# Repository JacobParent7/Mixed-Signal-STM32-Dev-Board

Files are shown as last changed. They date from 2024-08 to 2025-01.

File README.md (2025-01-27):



# Mixed-Signal-STM32-Dev-Board

This project follows the  [Mixed-Signal Hardware Design with KiCad](https://fedevel.com/courses/mixed-signal-hardware-design-with-kicad) 4-layer PCB design course instructed by Philip Salmony of the Phil's Lab youtube channel.  

Thank you to PCBWay for sponsoring the PCB fabrication and assembly for this complex mixed-signal board! 

Check our their services at https://www.pcbway.com/

0x0-2426178651

## System Level Description
### Basic Requirements
    - USB powered, single channel, low frequency analysis and generation capabilities
    - Perform frequency analysis and arbitrary signal generation
### Feature Specific Requirements
    - USB - <500mA current consumption 
    - Low Frequency - 20Hz - 20kHz (audio band)
    - ADC and DAC (or codec) for analysis and generation, single channel 
### Simple Block Diagram  
SimpleBlockDiagram
### Refine requirements
    - USB - low bandwidth and transfer requirements
    - Sample at Nyquist limit (40kHz)
    - Choose higher resolution ADC to minimize quantisation error
datarate
### USB Standard
    - Full Speed - Up to 12 Mbits/s (this is plenty enough)
    - High Speed - Up to 480 Mbits/s
    - System is bus powered (not a host) and will most likely require <500mA
    - Use type C, new universal standard
### Processor
    - Low bandwidth and storage requirements so FPGA unnecessary
    - Use MCU
        - C easy compared to Verilog
        - SWD or JTAG protocols available 
    - Peripherals
        - USB for data stream
        - SPI for ADC and DAC
    - Required Power?
        - Cortex M0 should be adequate 
        - Avoid BGA or QFN packages (too expensive and benefits not necessary for our use case) 
        - I know STM32 platform well
### PSU
    - Digital Circuitry Supply
        - Switch mode supply is noisy but more efficient than LDO. Works for resillient digital circuitry
    - Analog Circuitry Supply
        - LDO for low noise
        - Less current required compared to digital circuitry typically
    - Power from USB
        - Must regulate due to noise
        - +5V nominal, can drop to +4.5V
        - 500mA can be negotiated, but 150mA is default so design for that

### Simple Converter Theory
    - Higher bits gives better signal to noise ratio
    - Higher sampling rate provides less aliasing with a higher Nyquist limit, however this produces more data to store, process, and stream
    - Consider using oversampling and antialiasing filters on the convert ICs themselves
    - Interface with SPI since data rate is low (typical for microcontrollers)
    
### Analog Circuitry for Converters
    - ADC
        - High-impedance (don't attenuate original signal), ESD protection, RF filtering
        - Antialiasing filter at 1/2 the sampling frequency (Nyquist Rate)
        - Single ended vs differential compatibility
    - DAC
        - Low-impedance with output buffer for driving a load
        - Antialiasing filter at 1/2 the sampling frequency (Nyquist Rate) 
        - Single ended vs differential compatibility

### Miscellaneous Requirements
    - Mechanical Constraints
        - PCB dimensions
        - Mounting Holes
        - Connector Placement
        - Conductive Case?
    - Connectors
        - Debugging interface
        - IO types (SMA, BNC)
    - Peripherals
        - LEDs?
    - Other
        - Timing
        - ESD protection
        - EMC filtering
        - Biasing for analog circuitry 
### Final Block Diagram
finalblockdiagram

## Schematic Design - Power


### Input Pi Filter
    - The input RLC Pi filter from the USB-C has an inductor with a DC resistance of 0.15 Ohms and max DC of 0.5A
    - http://sim.okawa-denshi.jp/en/Fkeisan.htm -> Tools for filter design 
    - Using the website, we can see the Pi Filter has a cutoff in the 1.6 MHz range. For PSU, we want to keep the cutoff high to dampen high frequency noise
    - Be careful; IC transients are hungry for high frequency current and you don't want to starve them. Cutoff only what is needed to pass EMI tests. 
    


### Analog LDO regulator - HT75xx
    - Datasheet says to use at least 10uF for input and output caps. We use 22uF to avoid issues due to tolerances and voltage derating. 
    - Series Input resistor with at least 1/8W power rating creates low-pass filter RC with 22uF input capacitor
    - In general, RC filters have a much shallower roll-off compared to the RLC Pi Filter. They also have significant Johnson noise. 
    - Input low-pass has cutoff at 723 Hz. This is low but okay because it feeds a low freq analog supply. 

### Buck Converter
    - Main external circuitry
        - Input caps
        - Output LC filter - use below formula to calculate inductor value
        - Feedback network (formula straight from datasheet and also in schematic) 
        - Sometimes external FETs and diodes
#### [Choosing Inductor Value]
        - Delta IL is ripple current - try to get 20% - 30% of max output current
        - Design for worst case
            - Larger Vin
            - Low current loads
        - Choosing larger inductor than initially calculated
            - +- 20% typical tolerance
            - Max DC and sat current need to be higher than what we require in our worst peak current case (250mA)
            - Low current loads (down to 50mA) will require larger inductors
            - Is shielding important to us?
        - Plotting below function in DESMOS we see lighter loads require much larger inductance (6x) what we calculated, so we chose a 68 uF inductor
        - Although datasheet says we can use 4.7uF minimum caps, we want to consolidate our BOM, so choose 22uF as required by LDO
#### [DNP???]
    - We have a DNP (Do not place) cap because the datasheet recommends it for stability and speed
    - We still want the option to place it, so we will put pads on the PCB for it. 


### Bias Generator
    - We have a single supply 0V -> 3.3 V
    - Bias an input to 1/2 VA to give max swing potential for superimposed AC signal 
    - Provide bypass cap as recommended by datasheet (place physically close on board)
    - In high freq designs, the voltage and ground planes seperated by a dielectric board material create a low value high speed capacitor. 

## Schematic Design - MCU

### MCU Digital Power Decoupling
    - As recommended by the datasheet, we have a 100uF cap for each digital power input for a total of four caps
    - We also have on 10uF bulk decoupling cap, also recommended by the datasheet


### MCU Analog Power Decoupling
    - We do not need to do this because we are using external DAC and ADC
    - Below shows the datasheet implementation if this were not the case


### Config pins and Crystal Oscillator
    - NRST typically pulled high by internal 40k resistor. Route to SWD header for more control
    - BOOT0 on most STM32 uC. Tells chip to either run program flashed (low) or to listen for debug signals on UART or USB (high)
    - HSE_IN and HSE_OUT are our STM32 chips pins for an external crystal oscillator. Internal osc is okay for some applications, but not really accurate enough for UART or USB communication. 
    - The load capacitance (10p), ESR, and frequency of the crystal can all be found in the datasheet. 
    - For more info on calculating load caps, find AN2867 design guide for crystal oscillators. 



## Microcontroller Pin Layout
    - The datasheet for any given uC will specify what functions the uC pins can serve. However, we can take advantage of the STM32 Cube IDE to do this for us and save time
### Pin layout description
    - Under SYS, set up serial wire debug for communication. Choose trace asynchronous Sw for live plotting or monitoring.
    - Under RCC, choose HSE to be crystal resonator for external circuitry
    - Under TIM, we can choose timer channels for PWM generation for LEDs. 
    - Under connectivity, set up receiving and transmitting master SPI channels for ADC and DAC. Choose check box under USB for full speed USB.



### Moving to KiCAD
    - Once you choose the desired pin configuration in Cube IDE, move back to KiCAD and map pins to schematic symbol shown below
    - Add pull up resistors on SPI hardware and chip select lines (not necessary if driven by GPIO), however, we are using hardware chip select pin from SPI drivers
    - On USB diff pair, name + and - to tell KiCAD to map as diff pair.
    - Check application note for STM32F1 to see if embededded pullup is included on D+ line. When we check our application note, we can see that an external 1.5 KOhm pullup is required.


## USB, RGB LED, and SWD header

### RGB LED
    - simple 1k current limiting resistors, chosen mostly for BOM consolidation since we are driving using PWM
    - decoupling capacitor since the LEDs are driven by PWM



### USB connector
    - Power and data connections are main 
    - USB C has more pins than typical USB A
    - Read AN4879 application note for specefics on USB layout
    - Supply is noisy, so use a filter like a Pi Filter and RLC filter (seen in PSU section above) 
    - Add ESD protection with low capacitance since we are using a relatively high bandwidth 
    - Data line filtering via common-mode choke will reduce signal integrity but improve EMC performance (not really needed for USB 2.0)
#### USB Type C specifics
    - TA0357 application note from ST
    - Instead of drawing 5V at 5mA, we can use a type C power delivery IC and get 100W (5A at 20 V). This is not required for our project.
    - Tell host we want to draw power by having seperate 5.1k pulldown resistors on CC1 and CC2 pins, where CC stands for configuration channel (Make sure to use two seperate resistors!)
#### Common mode choke specifics
    - Choke must be rated for USB 2 frequency range and not impede too much
    - Choke will have a differential impedance which must match the USB bus impedance (90 Ohm)
#### Specify signal path for readability 
    - Connector -> ESD -> CM Choke -> Pull-Up -> MCU



### SWD Header
    - Look up SWD pinout on google for easy specification
    - SWD is a simple in-circuit debugging and programming method that requires only data and clock lines
    - ST uses ST-Link to make debugging very easy 
    - Include bi-directional TVS diodes on signal lines for protection 
    - Low-pass filter included on NRST line to prevent unwanted resets due to high frequency noise
#### SWD signals explained
    - Main signals are SWDIO and SWCLK
    - SWDIO is bidirectional data
    - SWCLK is clock signal 
    - SWO is an optional signal (trace line from earlier) which allows us to trace output in real time
    - NRST is a pin that if pulled low triggers a hard reset



## ADC & Analog Front End

### ADC IC
    - ADC schematic follows design suggestion from datasheet
    - Seperate Bulk decoupling caps for analog and digital power (use similar caps for BOM consolidation)
    - Shared ground (not good idea to split mixed signal ground)
    - Clock signal has 0 Ohm resistor. Series resistor may reduce EMI and ringing (replace with 22 Ohm for example)
    - Dedicated 3.3V analog reference (U3D2) significantly improves ADC accuracy 
    - PI network used to filter noisy 5V bus from USB. Choose resisitor wisely based on current sink from analog reference. 
ADC

### ADC Front-End
#### Front-End Role
    - Impedance conversion (low to high impednace input)
    - Anti-aliasing filter
#### Componenet Selection (From left to right)
    - BNC standard connector
    - ESD Protection from TVS diode
    - Perform RF filtering (AM or FM radio) @ 1.1 Mhz
    - 1k series resistor garuntees 1k minimum for lowpass filter, although it is likely the connecting device can provide higher impedance
    - C301 acts as decoupling cap for the single power rail Op-Amp
    - R301 and R302 in parallel create input impedance of 1.1 MOhm. This high impedance prevents loading the input
    - R301 and R302 are not in series with the signal path and are simply bias setting resistors. Therefore, they contribute little to Johnson Noise despite their large value. 
    - VCOM is from bias generator in PSU section 
    - R301, R302. and C301 form a high pass filter @1.4 Hz
    - First Op-Amp acts as follower (unity gain high impedance CMOS buffer). Power rail required decoupling cap 
    - Second Op-Amp is a third order sallen-key filter topology. Read below section for more info.
    - Feed resistor (R306) protects from shorts and forms a RC lowpass
    - We want to use single ended, so ADC_IN + and - need a common mode DC. 
#### Sallen-Key filters
    - Active filter (VCVS filter)
    - Low pass anti-aliasing (or reconstruction for DAC) filter
    - Limit bandwidth of sampled signal 
    - Cutoff set to nyquist limit
    - Our filter is a 3rd order (look at # of filtering caps) butterworth coefficient type filter with cutoff @ 25 kHz
    - Butterworth gives maximially flat response as opposed to Chebyshev (roll-off) or Bessel (time-domain responses)
    - http://sim.okawa-denshi.jp/en/Sallenkey3Lowkeisan.htm -> design tool

ADC2

## DAC & Output Stage
    - Second output pulled to ground to reduce noise
    - Internal ref is used for simplicity, decoupled according to datasheet
    - Digital supply used to keep analog supply clean 
    - Same 3rd order Sallen-Key anti-aliasing reconstruction filter
    - DAC outputs do not require AC coupling because bias is generated by the DAC input
    - 50 Ohm output impedance to define Op-AMp output
    - TVS for BNC ESD protection 
DAC

## PCB Layout Specifications

### PCB Stack-Up
    - SIG | GND | VCC | SIG
        - Easier for routing
    - SIG | GND | GND | SIG
        - Energy flows in dielectric between waveguiding copper. Therefore, this setup gives minimal return pad length for signals (single-ended) on both sides. 
        - Routing power through traces is not really a problem for an audio frequency design 
### Trace size rule of thumb    
    - 0.5mm for power
    - 0.3mm for signal
    - Spacing: 3x dielectric thickness to help with crosstalk noise
    - Always minimise length and maximize spacing

### Controlled impedance traces
    - Need to consider if rise/fall times of digital signals or highest frequency of analog signals are comparable to the propagation lengths of the PCB traces
    - High speed digital bus (USB, PCIe,...) and RF should always be routed as controlled impedance
    - We control impedances to match the impedance of the driver and receiver to minimize reflections
    - Trace impedance is approximated by inductance and capacitance of trace
        - Inductance has to do with the area of the loop
        - Capacitance has to do with the suface area
    - Use PCB fab calulator to find width for microstrip and diff pair traces





### Via Sizing
    - Small: 0.45mm pad with 0.25mm drill
    - Mediumn: 0.7mm pad with 0.3mm drill
    - Large: 0.8mm pad with 0.4mm drill
    - Use medium if possible for best cost 
    - Large is good for higher currents and small if contrained for space

## PCB Layout

### MCU
    - Keep decoupling caps as close to associated pins as possible
    - Pullups and downs can be put pretty much anywhere. Put in line with uC pin
    - Crystal oscillator should be kept away from switching components like the PSU


### ADC
    - ADC chip itself has and analog and digital side. We will use this to seperate the remainder of the layout
    - In general, keep loops as short as possible
    - Decoupling as close to IC as possible
    - Try to keep a clean signal line to eliminate stubs
    - Compressed diff pair into t shape which decreased coupling. This is fine because it's really a pseudo diff pair
    


### DAC    
    - DAC is simply just follow same layout as ADC for recontruction filter

### Linear and Switching PSU
    - Follow datasheets for ICs

### Rough Draft Layout Render

Nemesis-MixSigPCB

### Final Layout

    - 5V and 3.3 Power were routed last and planned mostly on the back
    - GND Via inlcuded for every signal or power via since we are using the board build up previously mentioned with 2 GND planes. This reduces EMI. 
    - All signals were routed as 50 Ohms controlled impedance which was 0.29mm. All power traces were 0.5mm
    - Diff pair was routed as .21 mm as calculated on expected manufacturers website. 
    - Digital and Analog portions were kept as far apart as possible
    - Use polygons instead of traces to connect Power that is near each other. 



### What is left?
    - Sticthing vias
    - Cleaner Routing
    - Silkscreen
    - Prepare for manufacturing

### Final 3D Render

Nemesis-MixSigPCB_Final

### Final Manufactured and Assembled PCB
    - Thanks to PCBWay for this flawless PCB. Throughout the manufacturing process, the engineers
    at PCBWay found a few errors in my design which were fixed for no extra cost. The process was quick 
    and I received the PCB soon after placing my order. 



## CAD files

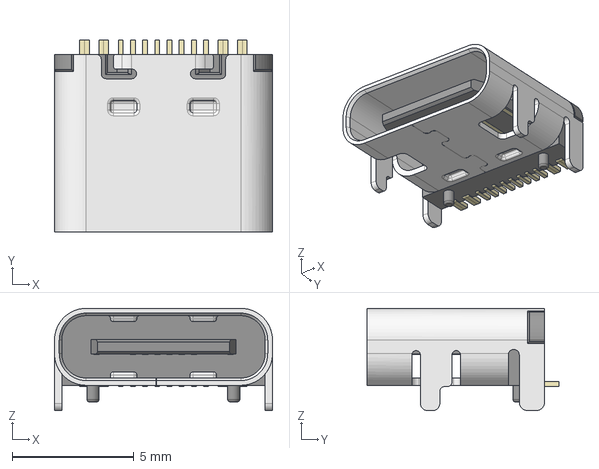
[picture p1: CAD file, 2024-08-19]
HRO_TYPE-C-31-M-12.step
8.95 x 7.90 x 4.20 mm

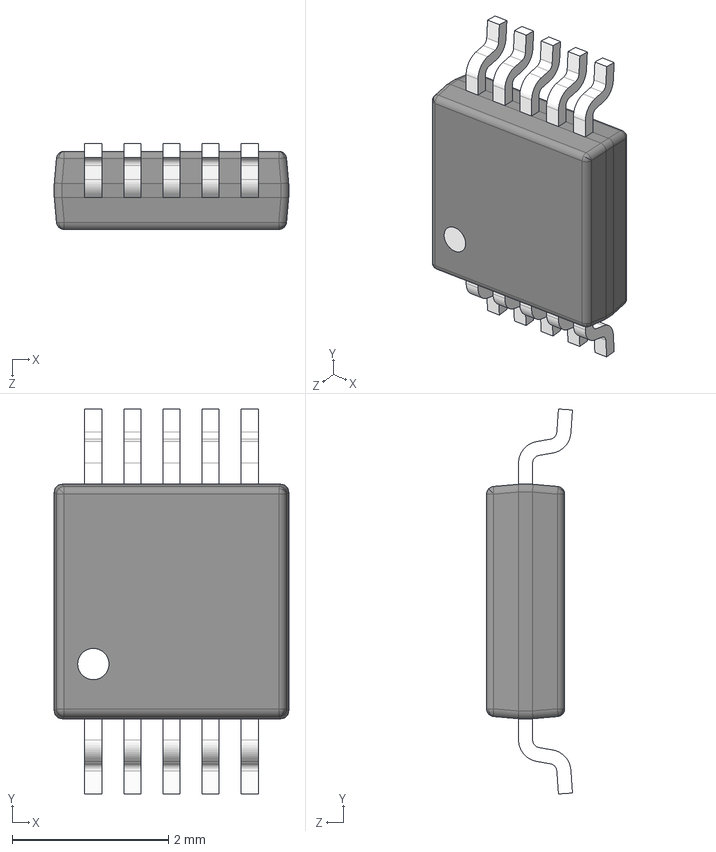
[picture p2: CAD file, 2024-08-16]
User Library-DGS0010A.STEP
3.00 x 4.93 x 1.10 mm
DGS0010A_ASM_LEAD-SO#LEAD-SO;LEAD-SO
DGS0010A_ASM_LEAD-SO#LEAD-SO;LEAD-SO_2
DGS0010A_ASM_LEAD-SO#LEAD-SO;LEAD-SO_3
DGS0010A_ASM_LEAD-SO#LEAD-SO;LEAD-SO_4
DGS0010A_ASM_LEAD-SO#LEAD-SO;LEAD-SO_5
DGS0010A_ASM_LEAD-SO#LEAD-SO;LEAD-SO_6
DGS0010A_ASM_LEAD-SO#LEAD-SO;LEAD-SO_7
DGS0010A_ASM_LEAD-SO#LEAD-SO;LEAD-SO_8
DGS0010A_ASM_LEAD-SO#LEAD-SO;LEAD-SO_9
DGS0010A_ASM_LEAD-SO#LEAD-SO;LEAD-SO_10
DGS0010A_ASM_BODY-SO#BODY-SO;BODY-SO

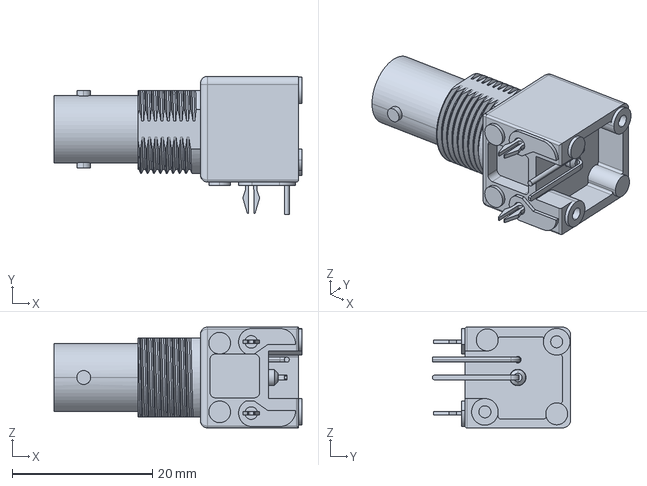
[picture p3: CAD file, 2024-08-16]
bnc.stp
35.4 x 19.8 x 14.4 mm

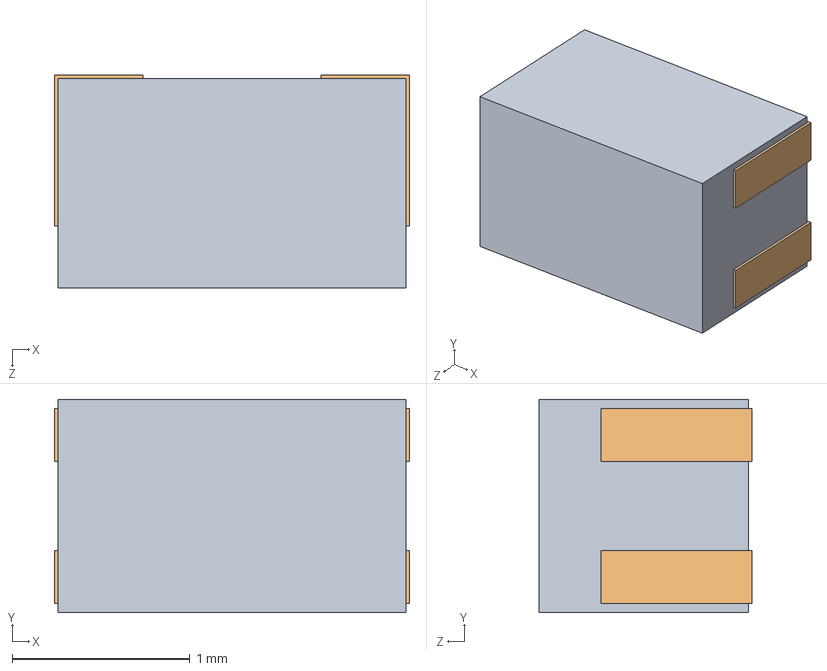
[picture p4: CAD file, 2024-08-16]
ACM2012-900-2P-T.stp
2.00 x 1.20 x 1.20 mm
ACM2012-T002 DRコアブロック(typ size)
ACM2012-T002 電極ブロック(typ size) x 4

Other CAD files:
VSSOP-10.STEP

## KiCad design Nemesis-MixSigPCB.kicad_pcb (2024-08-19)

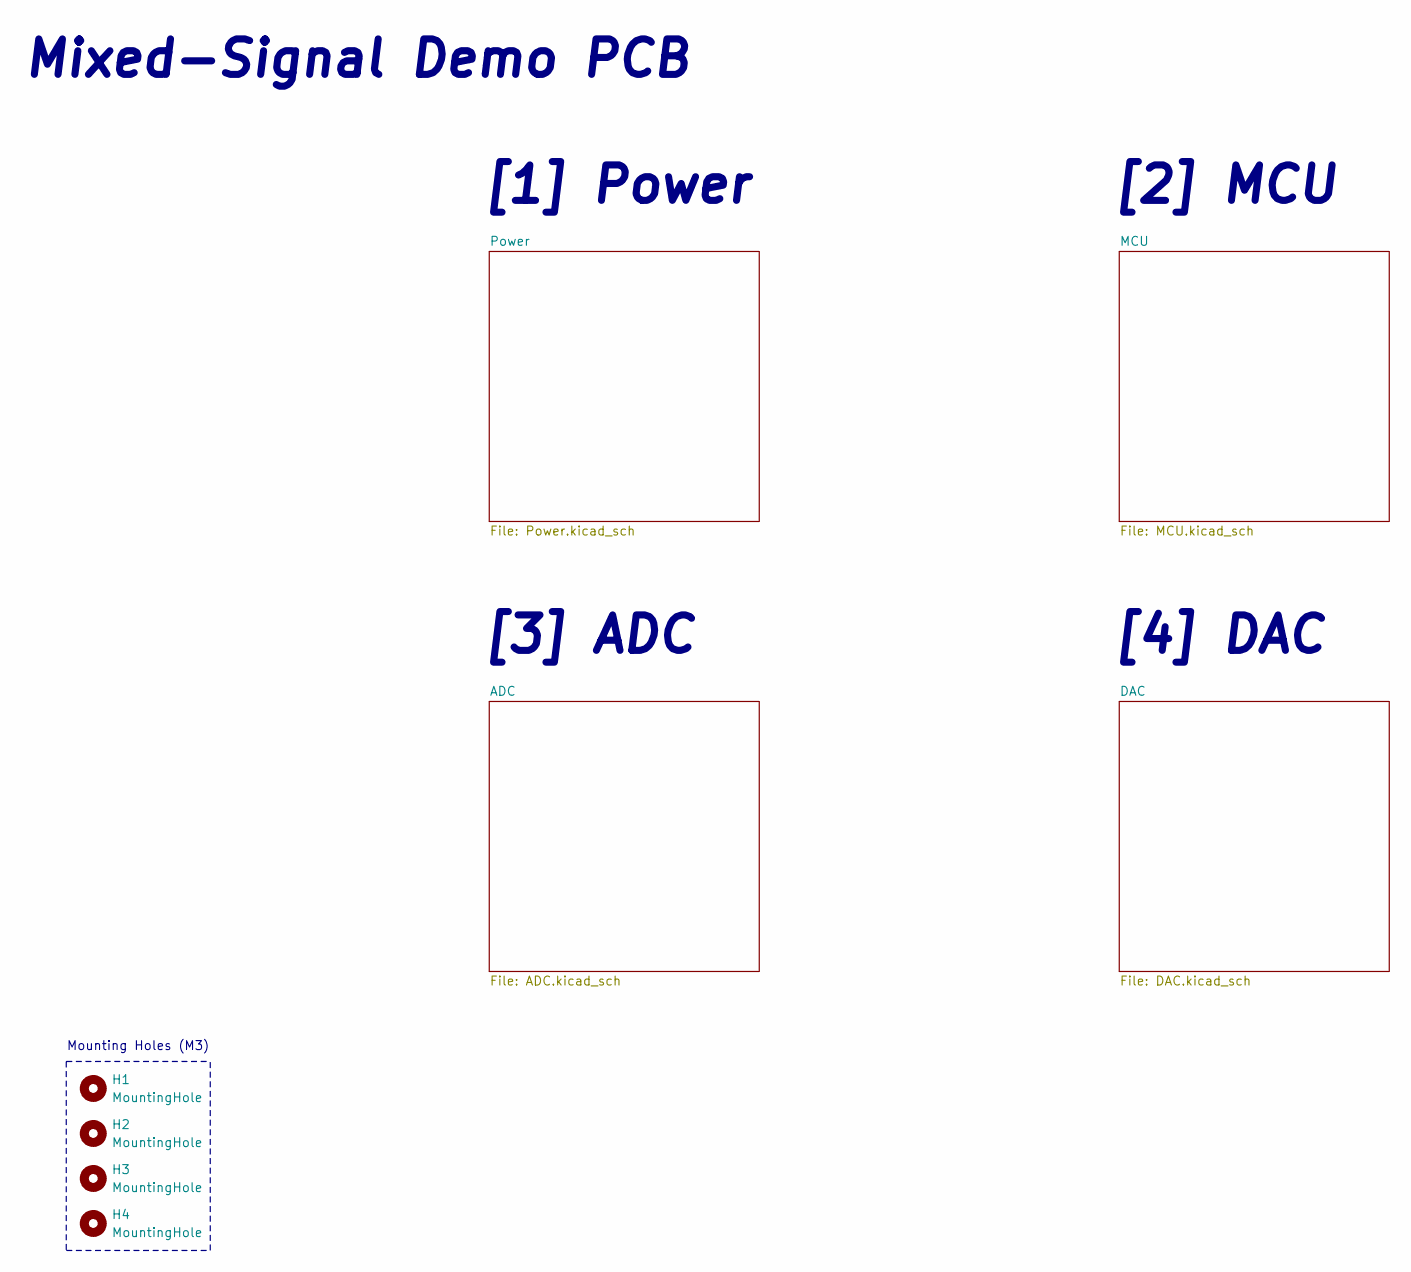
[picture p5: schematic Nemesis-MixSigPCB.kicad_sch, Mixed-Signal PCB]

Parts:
H1, H2, H3, H4: MountingHole; MountingHole_3.2mm_M3

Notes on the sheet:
[4] DAC
Mixed-Signal Demo PCB
[3] ADC
Mounting Holes (M3)
[2] MCU
[1] Power

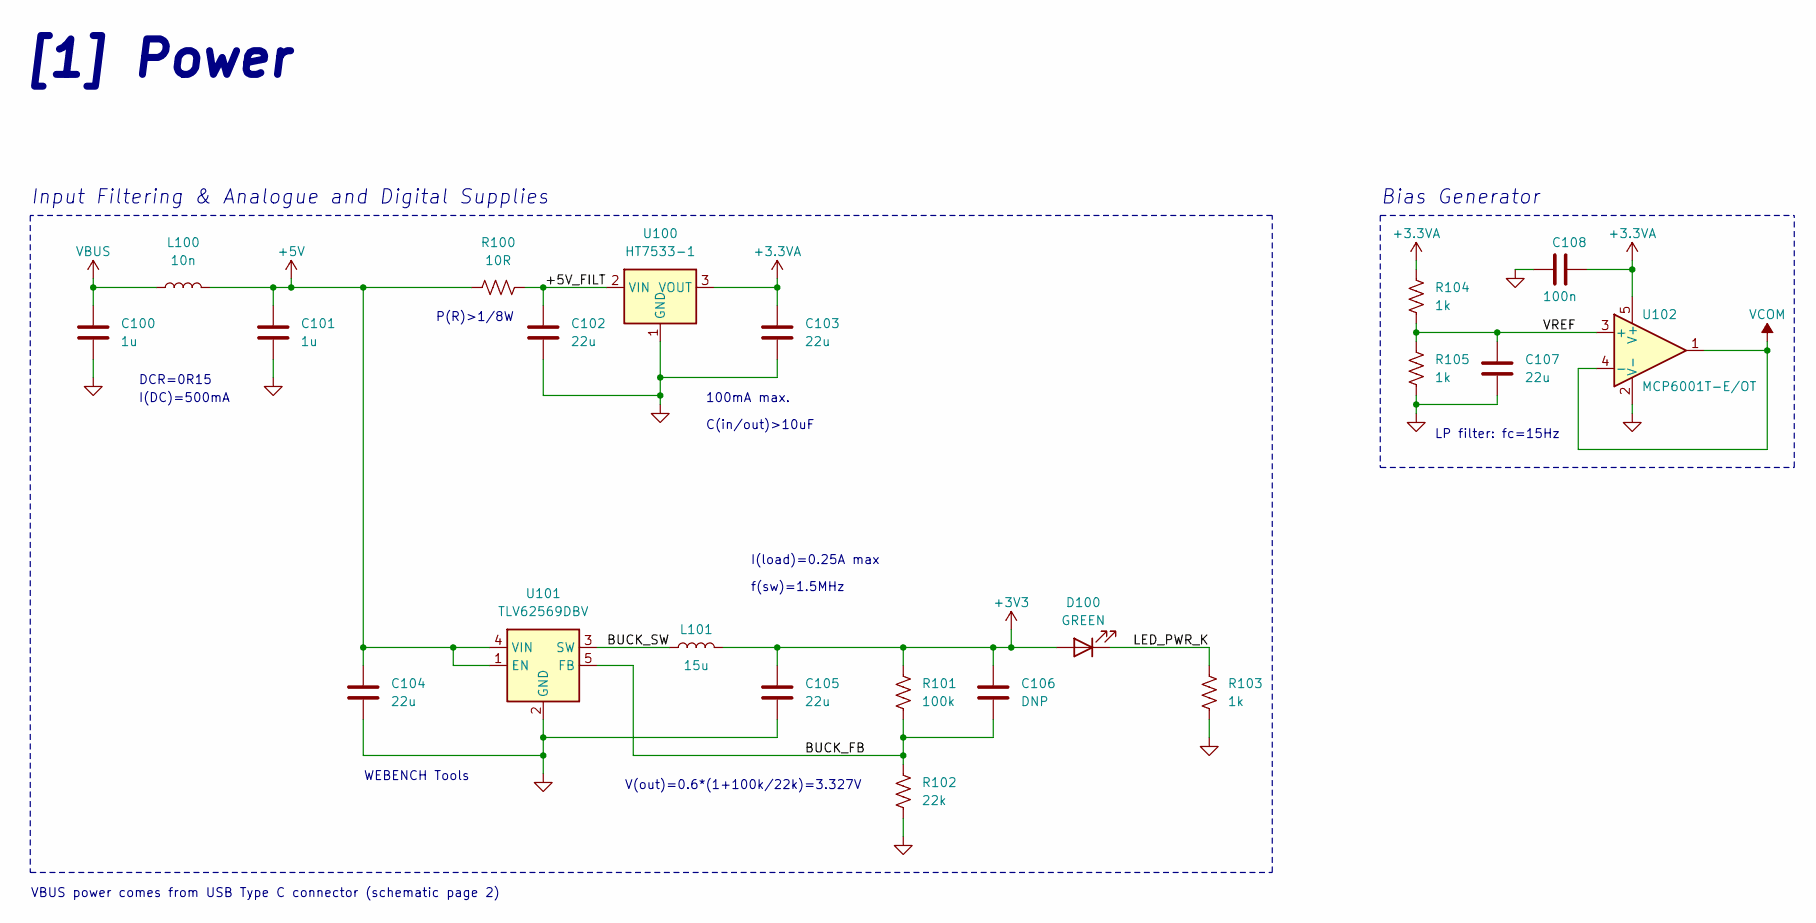
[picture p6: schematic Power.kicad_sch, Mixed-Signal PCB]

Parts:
C100, C101: 1u; C_0603_1608Metric
C102, C103, C104, C105, C107: 22u; C_0805_2012Metric
C106: DNP; C_0402_1005Metric
C108: 100n; C_0402_1005Metric
D100: GREEN; LED_0603_1608Metric
L100: 10n; L_0402_1005Metric
L101: 15u; L_Sunlord_MWSA0603S
R100: 10R; R_0805_2012Metric
R101: 100k; R_0402_1005Metric
R102: 22k; R_0402_1005Metric
R103, R104, R105: 1k; R_0402_1005Metric
U100: HT7533-1; SOT-89-3
U101: TLV62569DBV; SOT-23-5
U102: MCP6001T-E/OT; SOT-23-5

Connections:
+3.3VA: C103.1, C108.1, R104.2, U100.3 (VOUT), U102.5 (V+); also elsewhere on the board
+3V3: C105.1, C106.1, D100.2 (A), L101.2, R101.2; also elsewhere on the board
+5V: C101.1, C104.1, L100.2, R100.2, U101.1 (EN), U101.4 (VIN); also elsewhere on the board
/Power/+5V_FILT: C102.1, R100.1, U100.2 (VIN)
/Power/BUCK_FB: C106.2, R101.1, R102.2, U101.5 (FB)
/Power/BUCK_SW: L101.1, U101.3 (SW)
/Power/LED_PWR_K: D100.1 (K), R103.2
/Power/VREF: C107.1, R104.1, R105.2, U102.3 (+)
GND: C100.2, C101.2, C102.2, C103.2, C104.2, C105.2, C107.2, C108.2, R102.1, R103.1, R105.1, U100.1 (GND), U101.2 (GND), U102.2 (V-); also elsewhere on the board
VBUS: C100.1, L100.1; also elsewhere on the board
VCOM: U102.1, U102.4 (-); also elsewhere on the board

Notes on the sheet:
DCR=0R15
C(in/out)>10uF
V(out)=0.6*(1+100k/22k)=3.327V
I(DC)=500mA
Bias Generator
LP filter: fc=15Hz
100mA max.
f(sw)=1.5MHz
VBUS power comes from USB Type C connector (schematic page 2)
P(R)>1/8W
I(load)=0.25A max
Input Filtering & Analogue and Digital Supplies
[1] Power
WEBENCH Tools

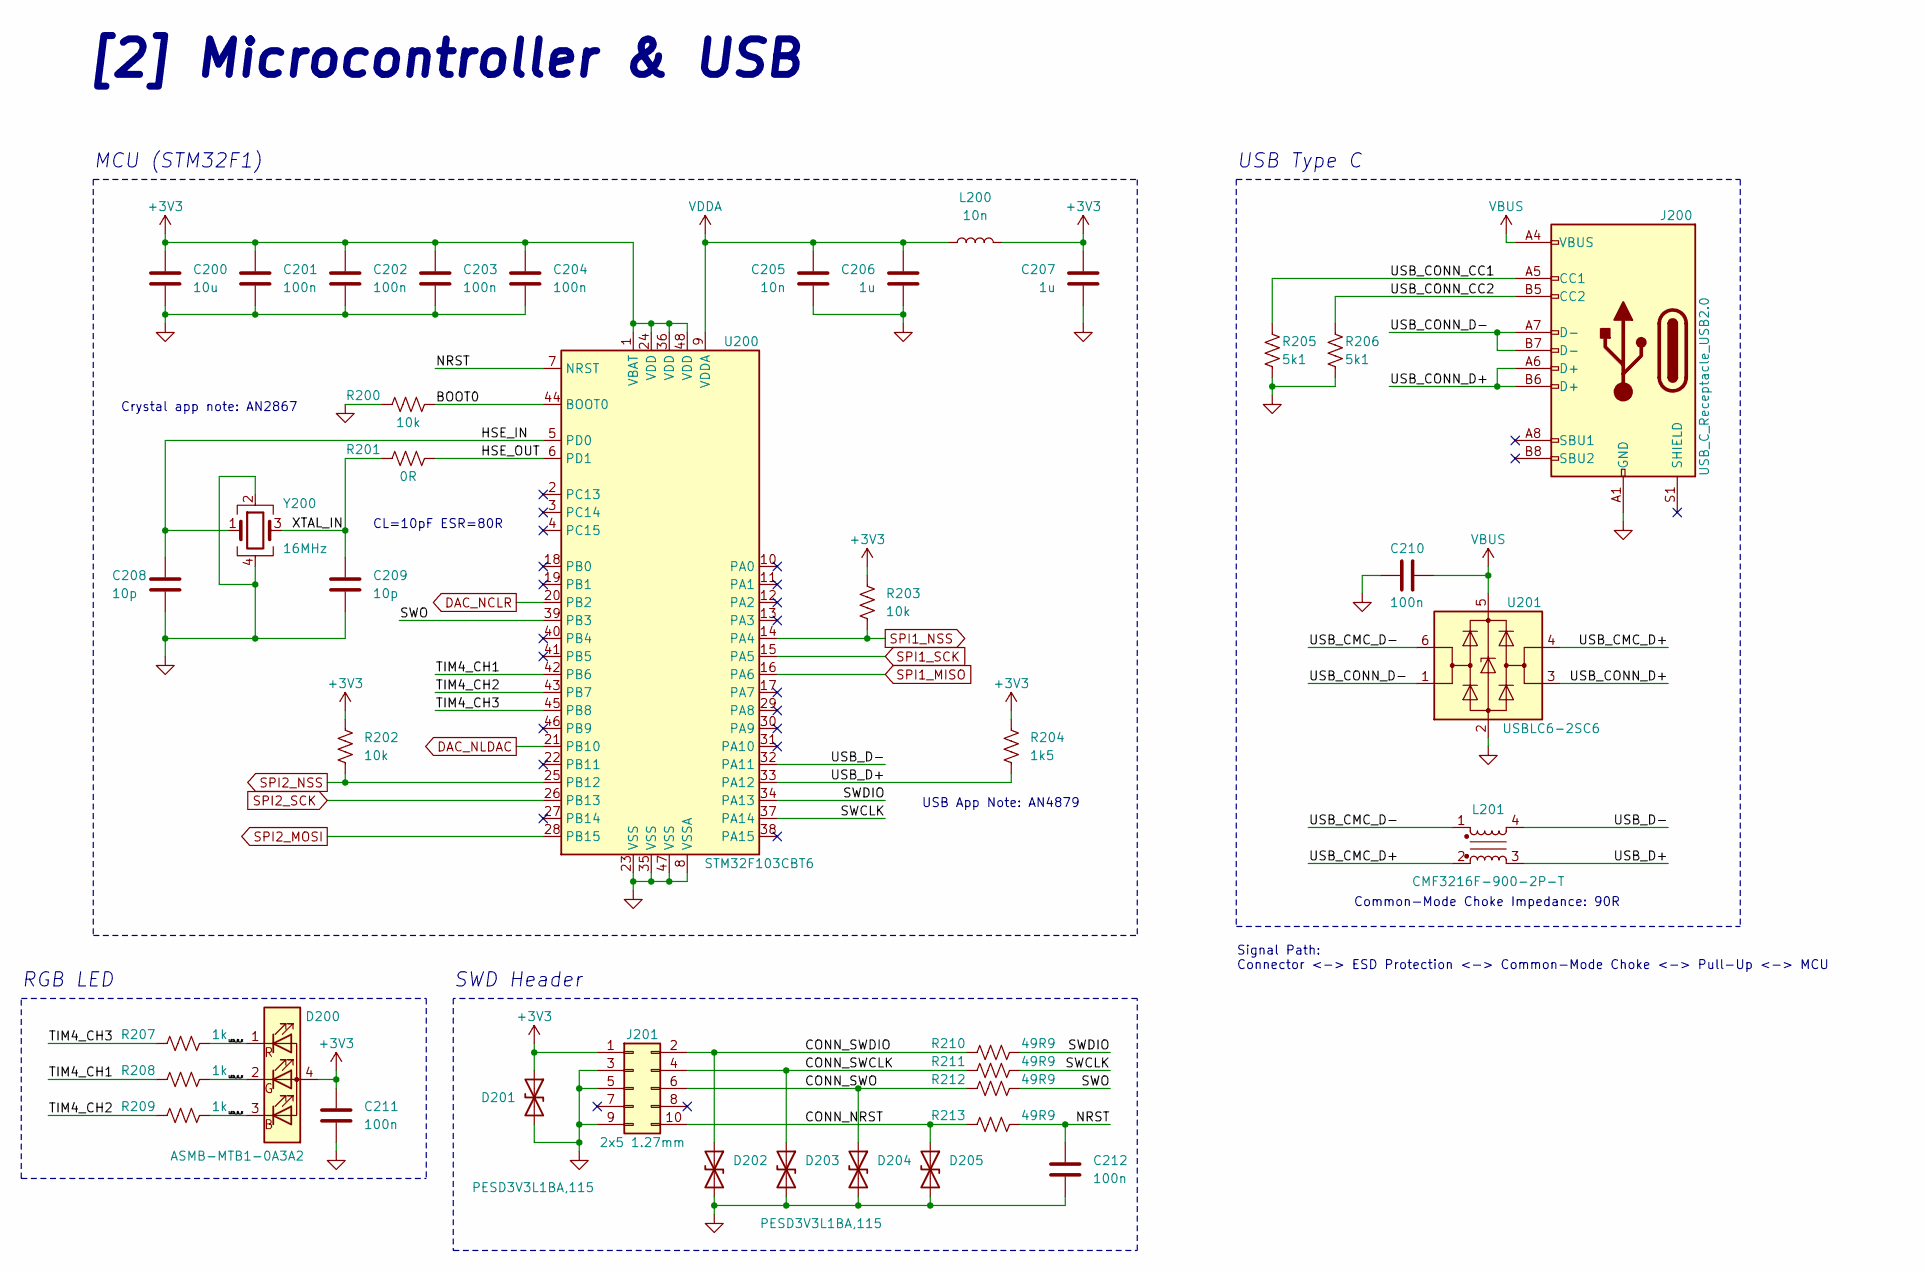
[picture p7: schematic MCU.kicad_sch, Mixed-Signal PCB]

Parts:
C200: 10u; C_0603_1608Metric
C201, C202, C203, C204, C210, C211, C212: 100n; C_0402_1005Metric
C205: 10n; C_0402_1005Metric
C206, C207: 1u; C_0603_1608Metric
C208, C209: 10p; C_0402_1005Metric
D200: ASMB-MTB1-0A3A2; LED_Avago_PLCC4_3.2x2.8mm_CW
D201, D202, D203, D204, D205: PESD3V3L1BA,115; D_SOD-323
J200: USB_C_Receptacle_USB2.0; USB_C_Receptacle_HRO_TYPE-C-31-M-12
J201: 2x5 1.27mm; PinHeader_2x05_P1.27mm_Vertical_SMD
L200: 10n; L_0402_1005Metric
L201: CMF3216F-900-2P-T; choke
R200, R202, R203: 10k; R_0402_1005Metric
R201: 0R; R_0402_1005Metric
R204: 1k5; R_0402_1005Metric
R205, R206: 5k1; R_0402_1005Metric
R207, R208, R209: 1k; R_0402_1005Metric
R210, R211, R212, R213: 49R9; R_0402_1005Metric
U200: STM32F103CBT6; LQFP-48_7x7mm_P0.5mm; Manufacturer Part Number STM32F103CBT6
U201: USBLC6-2SC6; SOT-23-6
Y200: 16MHz; Crystal_SMD_3225-4Pin_3.2x2.5mm

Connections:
+3V3: C200.1, C201.1, C202.1, C203.1, C204.1, C207.1, C211.1, D200.4 (A), D201.1 (A1), J201.1, L200.2, R202.1, R203.1, R204.1, U200.1 (VBAT), U200.24 (VDD), U200.36 (VDD), U200.48 (VDD); also elsewhere on the board
/MCU/BOOT0: R200.1, U200.44 (BOOT0)
/MCU/CONN_NRST: D205.1 (A1), J201.10, R213.2
/MCU/CONN_SWCLK: D203.1 (A1), J201.4, R211.2
/MCU/CONN_SWDIO: D202.1 (A1), J201.2, R210.2
/MCU/CONN_SWO: D204.1 (A1), J201.6, R212.2
/MCU/HSE_IN: C208.1, U200.5 (PD0), Y200.1
/MCU/HSE_OUT: R201.1, U200.6 (PD1)
/MCU/LED_B_K: D200.3 (BK), R209.2
/MCU/LED_G_K: D200.2 (GK), R208.2
/MCU/LED_R_K: D200.1 (RK), R207.2
/MCU/NRST: C212.1, R213.1, U200.7 (NRST)
/MCU/SWCLK: R211.1, U200.37 (PA14)
/MCU/SWDIO: R210.1, U200.34 (PA13)
/MCU/SWO: R212.1, U200.39 (PB3)
/MCU/TIM4_CH1: R208.1, U200.42 (PB6)
/MCU/TIM4_CH2: R209.1, U200.43 (PB7)
/MCU/TIM4_CH3: R207.1, U200.45 (PB8)
/MCU/USB_CMC_D+: L201.2, U201.4 (I/O2)
/MCU/USB_CMC_D-: L201.1, U201.6 (I/O1)
/MCU/USB_CONN_CC1: J200.A5 (CC1), R205.1
/MCU/USB_CONN_CC2: J200.B5 (CC2), R206.1
/MCU/USB_CONN_D+: J200.A6 (D+), J200.B6 (D+), U201.3 (I/O2)
/MCU/USB_CONN_D-: J200.A7 (D-), J200.B7 (D-), U201.1 (I/O1)
/MCU/USB_D+: L201.3, R204.2, U200.33 (PA12)
/MCU/USB_D-: L201.4, U200.32 (PA11)
/MCU/XTAL_IN: C209.1, R201.2, Y200.3
DAC_NCLR: U200.20 (PB2); also elsewhere on the board
DAC_NLDAC: U200.21 (PB10); also elsewhere on the board
GND: C200.2, C201.2, C202.2, C203.2, C204.2, C205.2, C206.2, C207.2, C208.2, C209.2, C210.2, C211.2, C212.2, D201.2 (A2), D202.2 (A2), D203.2 (A2), D204.2 (A2), D205.2 (A2), J200.A1 (GND), J200.A12 (GND), J200.B1 (GND), J200.B12 (GND), J201.3, J201.5, J201.9, R200.2, R205.2, R206.2, U200.8 (VSSA), U200.23 (VSS), U200.35 (VSS), U200.47 (VSS), U201.2 (GND), Y200.2, Y200.4; also elsewhere on the board
SPI1_MISO: U200.16 (PA6); also elsewhere on the board
SPI1_NSS: R203.2, U200.14 (PA4); also elsewhere on the board
SPI1_SCK: U200.15 (PA5); also elsewhere on the board
SPI2_MOSI: U200.28 (PB15); also elsewhere on the board
SPI2_NSS: R202.2, U200.25 (PB12); also elsewhere on the board
SPI2_SCK: U200.26 (PB13); also elsewhere on the board
VBUS: C210.1, J200.A4 (VBUS), J200.A9 (VBUS), J200.B4 (VBUS), J200.B9 (VBUS), U201.5 (VBUS); also elsewhere on the board
VDDA: C205.1, C206.1, L200.1, U200.9 (VDDA)

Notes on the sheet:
Signal Path: Connector <-> ESD Protection <-> Common-Mode Choke <-> Pull-Up <-> MCU
RGB LED
Crystal app note: AN2867
SWD Header
USB App Note: AN4879
Common-Mode Choke Impedance: 90R
[2] Microcontroller & USB
CL=10pF ESR=80R
MCU (STM32F1)
USB Type C

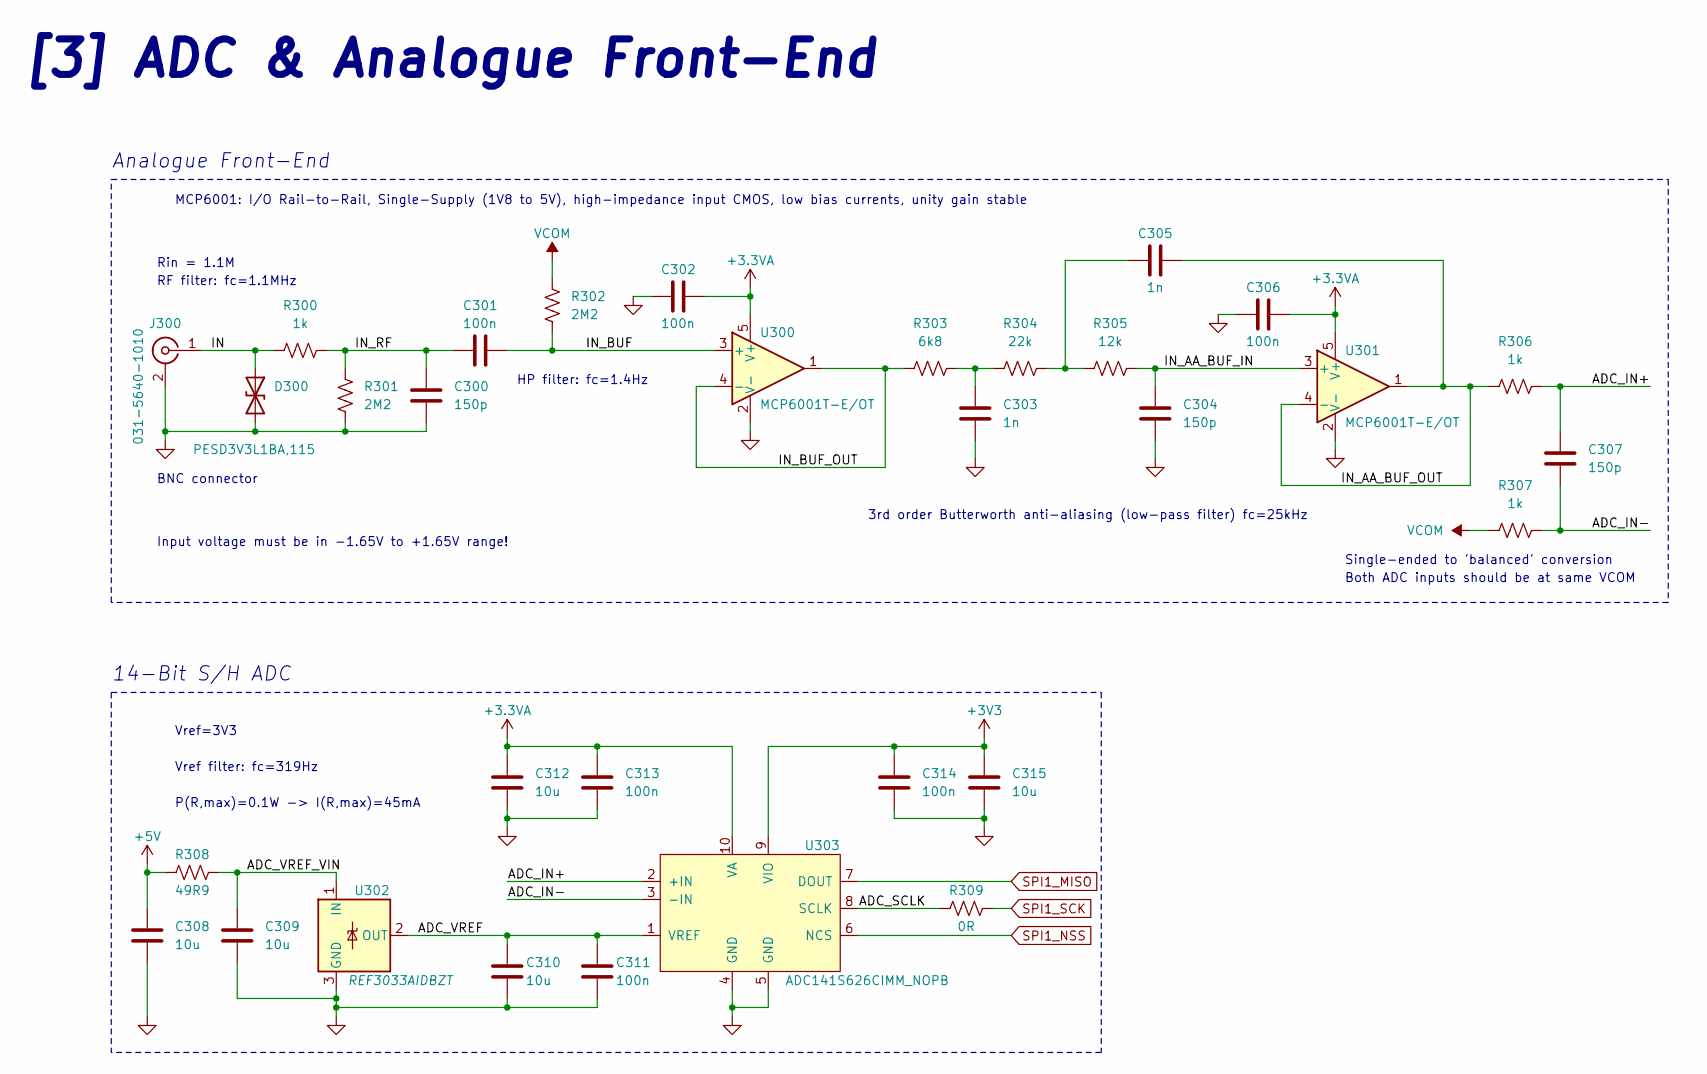
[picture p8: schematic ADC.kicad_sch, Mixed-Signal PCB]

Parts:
C300, C304, C307: 150p; C_0402_1005Metric
C301, C302, C306, C311, C313, C314: 100n; C_0402_1005Metric
C303, C305: 1n; C_0402_1005Metric
C308, C309, C310, C312, C315: 10u; C_0603_1608Metric
D300: PESD3V3L1BA,115; D_SOD-323
J300: 031-5640-1010; BNC
R300, R306, R307: 1k; R_0402_1005Metric
R301, R302: 2M2; R_0402_1005Metric
R303: 6k8; R_0402_1005Metric
R304: 22k; R_0402_1005Metric
R305: 12k; R_0402_1005Metric
R308: 49R9; R_0402_1005Metric
R309: 0R; R_0402_1005Metric
U300, U301: MCP6001T-E/OT; SOT-23-5
U302: REF3033AIDBZT; SOT-23
U303: ADC141S626CIMM_NOPB; SOIC-10

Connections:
+3.3VA: C302.1, C306.1, C312.1, C313.1, U300.5 (V+), U301.5 (V+), U303.10 (VA); also elsewhere on the board
+3V3: C314.1, C315.1, U303.9 (VIO); also elsewhere on the board
+5V: C308.1, R308.2; also elsewhere on the board
/ADC/ADC_IN+: C307.1, R306.1, U303.2 (+IN)
/ADC/ADC_IN-: C307.2, R307.1, U303.3 (-IN)
/ADC/ADC_SCLK: R309.2, U303.8 (SCLK)
/ADC/ADC_VREF: C310.1, C311.1, U302.2 (OUT), U303.1 (VREF)
/ADC/ADC_VREF_VIN: C309.1, R308.1, U302.1 (IN)
/ADC/IN: D300.1 (A1), J300.1 (In), R300.2
/ADC/IN_AA_BUF_IN: C304.1, R305.1, U301.3 (+)
/ADC/IN_AA_BUF_OUT: C305.2, R306.2, U301.1, U301.4 (-)
/ADC/IN_BUF: C301.1, R302.1, U300.3 (+)
/ADC/IN_BUF_OUT: R303.2, U300.1, U300.4 (-)
/ADC/IN_RF: C300.1, C301.2, R300.1, R301.2
GND: C300.2, C302.2, C303.2, C304.2, C306.2, C308.2, C309.2, C310.2, C311.2, C312.2, C313.2, C314.2, C315.2, D300.2 (A2), J300.2 (Ext), J300.3, J300.4, R301.1, U300.2 (V-), U301.2 (V-), U302.3 (GND), U303.4 (GND), U303.5 (GND); also elsewhere on the board
unnamed: C303.1, R303.1, R304.2
unnamed: C305.1, R304.1, R305.2
SPI1_MISO: U303.7 (DOUT); also elsewhere on the board
SPI1_NSS: U303.6 (NCS); also elsewhere on the board
SPI1_SCK: R309.1; also elsewhere on the board
VCOM: R302.2, R307.2; also elsewhere on the board

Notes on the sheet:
HP filter: fc=1.4Hz
Both ADC inputs should be at same VCOM
BNC connector
Rin = 1.1M
14-Bit S/H ADC
Vref filter: fc=319Hz
Input voltage must be in -1.65V to +1.65V range!
Analogue Front-End
Single-ended to 'balanced' conversion
RF filter: fc=1.1MHz
3rd order Butterworth anti-aliasing (low-pass filter) fc=25kHz
MCP6001: I/O Rail-to-Rail, Single-Supply (1V8 to 5V), high-impedance input CMOS, low bias currents, unity gain stable
P(R,max)=0.1W -> I(R,max)=45mA
Vref=3V3
[3] ADC & Analogue Front-End

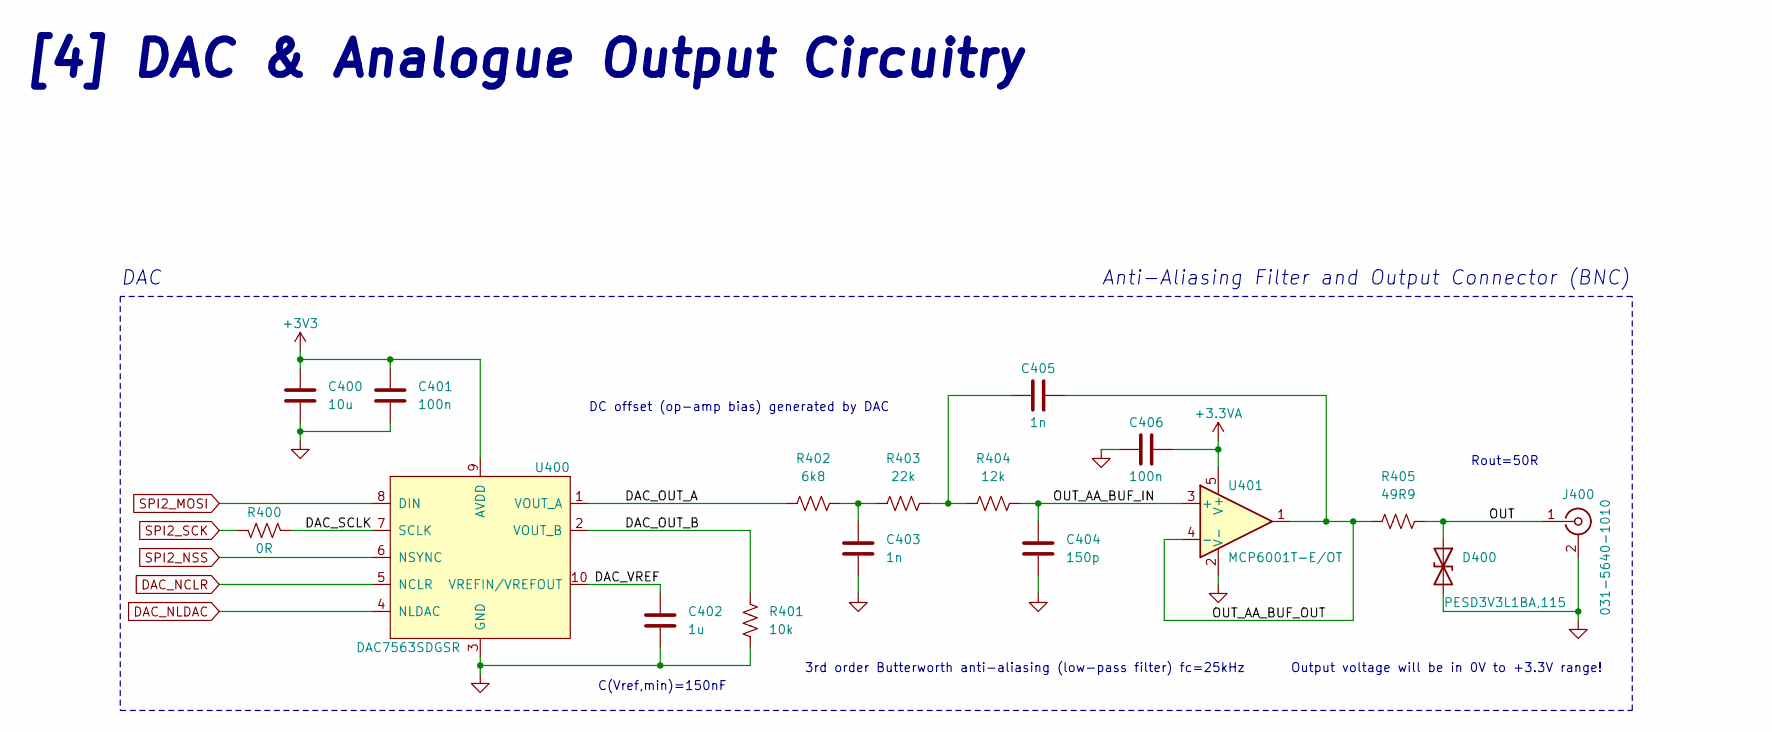
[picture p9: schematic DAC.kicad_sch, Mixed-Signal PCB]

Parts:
C400: 10u; C_0603_1608Metric
C401, C406: 100n; C_0402_1005Metric
C402: 1u; C_0603_1608Metric
C403, C405: 1n; C_0402_1005Metric
C404: 150p; C_0402_1005Metric
D400: PESD3V3L1BA,115; D_SOD-323
J400: 031-5640-1010; BNC
R400: 0R; R_0402_1005Metric
R401: 10k; R_0402_1005Metric
R402: 6k8; R_0402_1005Metric
R403: 22k; R_0402_1005Metric
R404: 12k; R_0402_1005Metric
R405: 49R9; R_0402_1005Metric
U400: DAC7563SDGSR; SOIC-10
U401: MCP6001T-E/OT; SOT-23-5

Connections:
+3.3VA: C406.1, U401.5 (V+); also elsewhere on the board
+3V3: C400.1, C401.1, U400.9 (AVDD); also elsewhere on the board
/DAC/DAC_OUT_A: R402.2, U400.1 (VOUT_A)
/DAC/DAC_OUT_B: R401.1, U400.2 (VOUT_B)
/DAC/DAC_SCLK: R400.2, U400.7 (SCLK)
/DAC/DAC_VREF: C402.1, U400.10 (VREFIN/VREFOUT)
/DAC/OUT: D400.1 (A1), J400.1 (In), R405.1
/DAC/OUT_AA_BUF_IN: C404.1, R404.1, U401.3 (+)
/DAC/OUT_AA_BUF_OUT: C405.2, R405.2, U401.1, U401.4 (-)
DAC_NCLR: U400.5 (NCLR); also elsewhere on the board
DAC_NLDAC: U400.4 (NLDAC); also elsewhere on the board
GND: C400.2, C401.2, C402.2, C403.2, C404.2, C406.2, D400.2 (A2), J400.2 (Ext), J400.3, J400.4, R401.2, U400.3 (GND), U401.2 (V-); also elsewhere on the board
unnamed: C403.1, R402.1, R403.2
unnamed: C405.1, R403.1, R404.2
SPI2_MOSI: U400.8 (DIN); also elsewhere on the board
SPI2_NSS: U400.6 (NSYNC); also elsewhere on the board
SPI2_SCK: R400.1; also elsewhere on the board

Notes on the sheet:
[4] DAC & Analogue Output Circuitry
Anti-Aliasing Filter and Output Connector (BNC)
Rout=50R
Output voltage will be in 0V to +3.3V range!
DAC
C(Vref,min)=150nF
3rd order Butterworth anti-aliasing (low-pass filter) fc=25kHz
DC offset (op-amp bias) generated by DAC

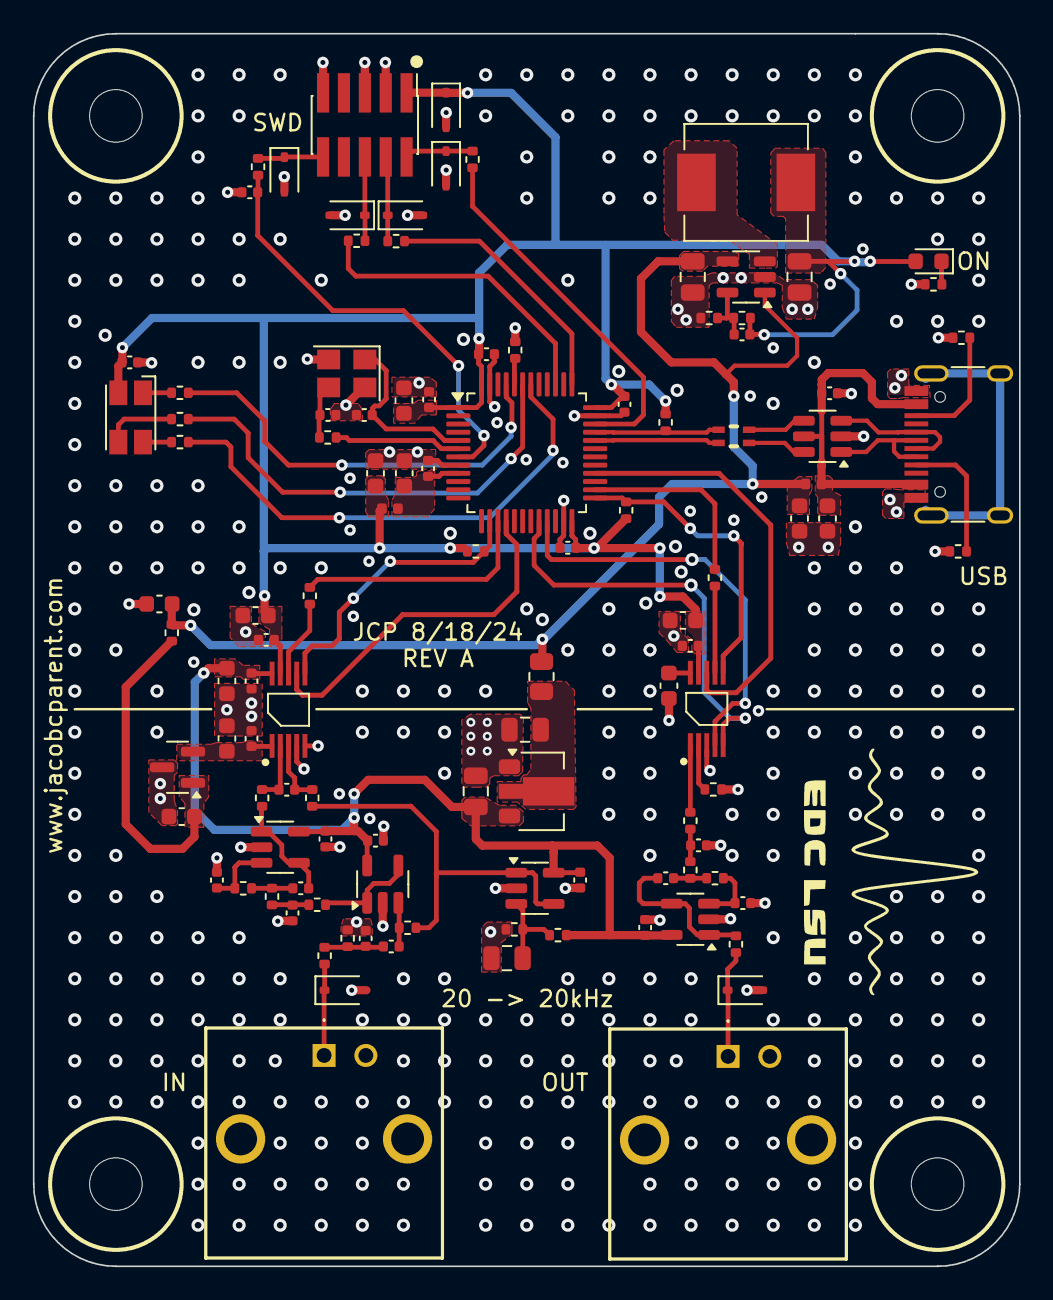
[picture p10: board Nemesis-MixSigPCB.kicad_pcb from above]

Board: 4 copper layers, 60.0 x 75.0 mm, 114 parts (0 on the bottom side), 68 nets.

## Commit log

2024-06-26 Initial schematic layout
    This commit includes the initial schematic layout and the finished PSU schematic.
    [ADC.kicad_sch, DAC.kicad_sch, MCU.kicad_sch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]
2024-07-28 Adding official files from course download
    [ADC.kicad_sch, ADC.sch, DAC.kicad_sch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]
2024-07-28 Add backup file and updates to schematic
    [ADC.kicad_sch, DAC.kicad_sch, MCU.kicad_sch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]
2024-08-19 Layout Complete
    Still need to add assembly files
    [HRO_TYPE-C-31-M-12.step, Nemesis-MixSigPCB.kicad_pcb]
